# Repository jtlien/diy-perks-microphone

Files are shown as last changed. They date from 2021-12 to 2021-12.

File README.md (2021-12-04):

# diy-perks-microphone
This is the Kicad implementation of a pc board for the DIY PERKS high performance microphone
Please become a subscriber to DIY PERKS channel on Youtube.
I have put this circuit into KICAD for those interested in putting it on a PC board.
I have not tested the board out yet.
The connection to the Volume control is a switch selecting one of 560 Ohm, 270 Ohm, 150 Ohm, 82 Ohm,
56 Ohm, 27 Ohm, 18 Ohm, 15 Ohm, 11 Ohm, 9.1 Ohm and 5.1 Ohm.
The microphone connection is to a 2N4416 Fet soldered directly to the outputs of the microphone cell.
The microphone capsule is a JLI2555.  I have included a .dxf file of the capsule case that has holes for the
sound.  It can be used to have the case made at an online laser cutting service.

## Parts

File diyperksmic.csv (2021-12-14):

Id | Designator | Package | Quantity | Designation | Supplier and ref
1 | J1 | PinHeader_1x03_P2.54mm_Vertical | 1 | Conn_01x03
2 | REF**,REF**,REF**,REF** | MountingHole_2.2mm_M2_DIN965 | 4 | MountingHole_2.2mm_M2_DIN965
3 | J2 | CUI_RCJ-042 | 1 | Conn_Coaxial
4 | R1 | R_Axial_DIN0309_L9.0mm_D3.2mm_P12.70mm_Horizontal | 1 | 2.2K
5 | R2,R4,R3 | R_Axial_DIN0309_L9.0mm_D3.2mm_P15.24mm_Horizontal | 3 | 2.2K
6 | C6,C7,C3,C4 | CP_Radial_D10.0mm_P3.80mm | 4 | 2200uF
7 | J4,J3 | TerminalBlock_Phoenix_MKDS-1,5-2_1x02_P5.00mm_Horizontal | 2 | Conn_01x02
8 | R8,R7 | R_Axial_DIN0309_L9.0mm_D3.2mm_P15.24mm_Horizontal | 2 | 100
9 | R6,R5 | R_Axial_DIN0309_L9.0mm_D3.2mm_P15.24mm_Horizontal | 2 | 3.9K
10 | U2 | Converter_DCDC_muRata_NMAxxxxSC_THT | 1 | NMA0515SC
11 | U1 | DIP-8_W7.62mm | 1 | THAT1512
12 | C1,C2,C5 | C_Disc_D8.0mm_W5.0mm_P5.00mm | 3 | 22uF

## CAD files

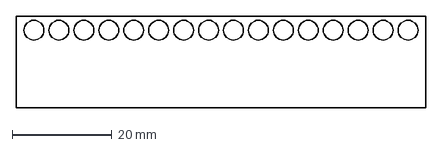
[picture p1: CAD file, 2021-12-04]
strip2.dxf
82.0 x 18.2 mm

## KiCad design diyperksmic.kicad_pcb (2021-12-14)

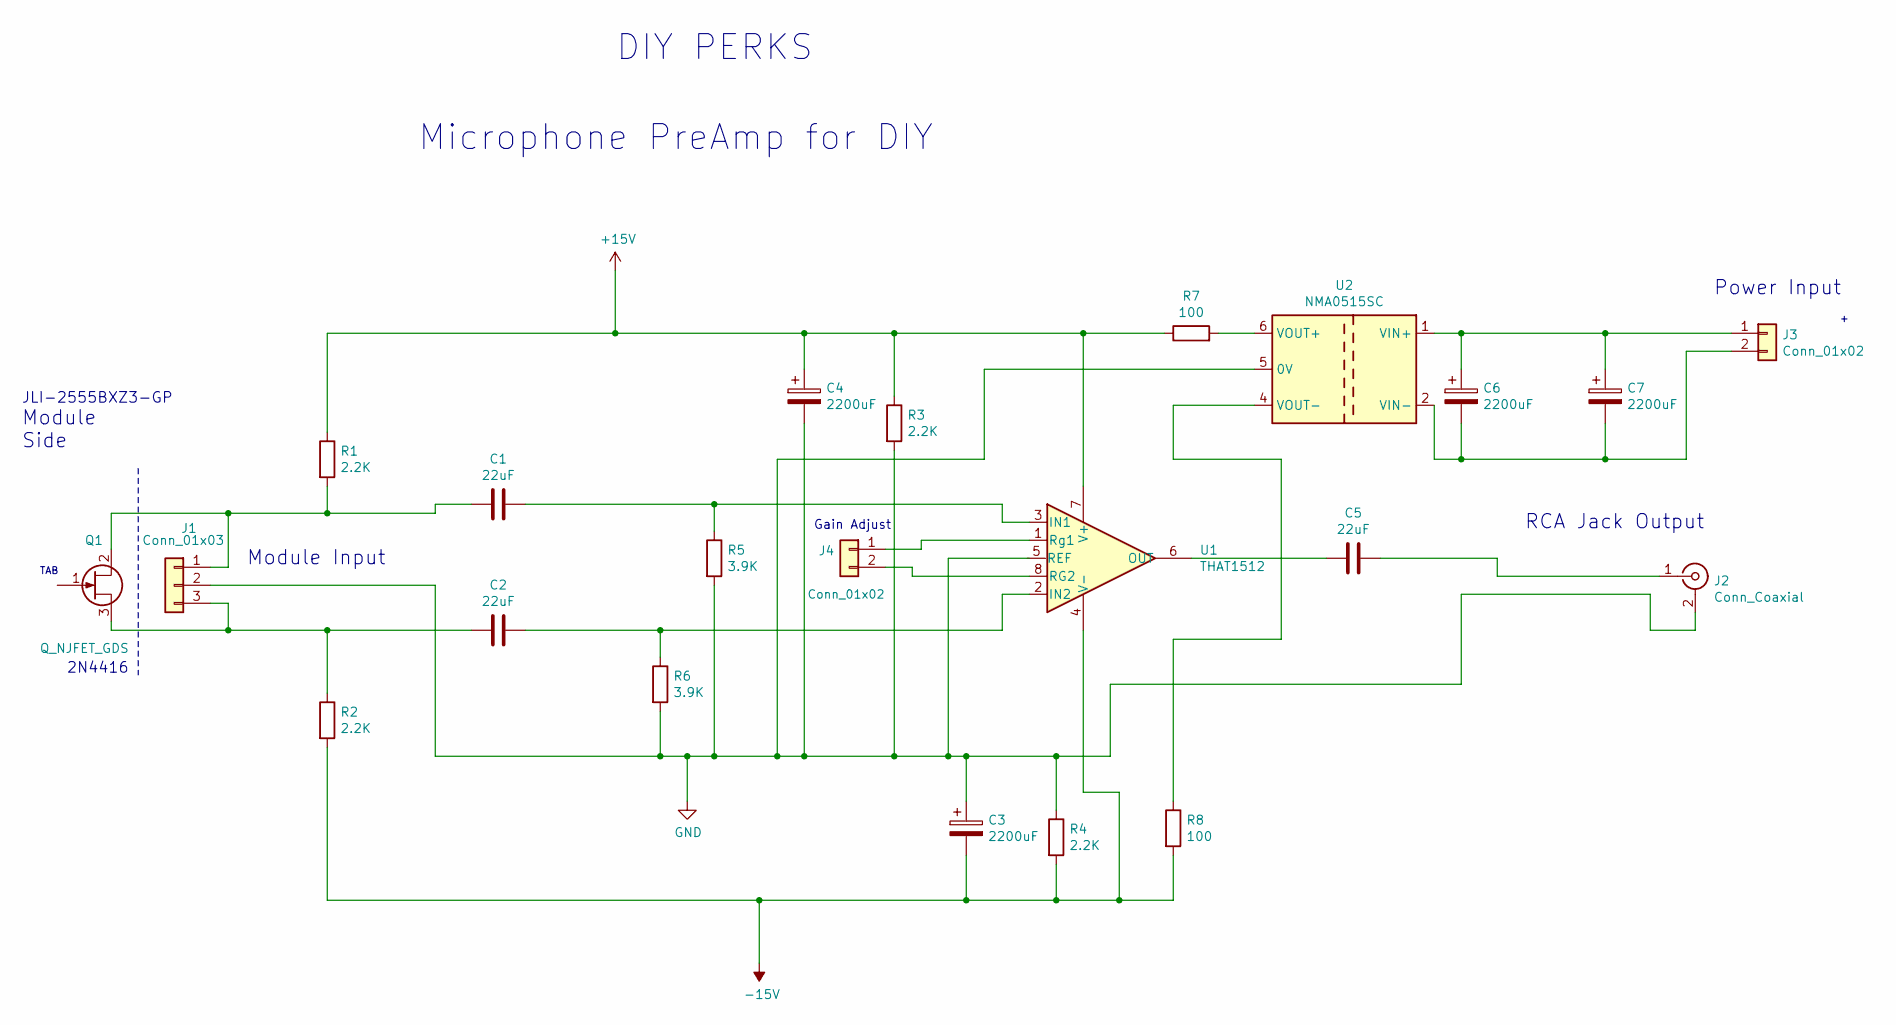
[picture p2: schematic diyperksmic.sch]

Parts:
C1, C2, C5: 22uF; C_Disc_D8.0mm_W5.0mm_P5.00mm
C3, C4, C6, C7: 2200uF; CP_Radial_D10.0mm_P3.80mm
J1: Conn_01x03; PinHeader_1x03_P2.54mm_Vertical
J2: Conn_Coaxial; CUI_RCJ-042
J3, J4: Conn_01x02; TerminalBlock_Phoenix_MKDS-1,5-2_1x02_P5.00mm_Horizontal
Q1: Q_NJFET_GDS
R1, R2, R3, R4: 2.2K; R_Axial_DIN0207_L6.3mm_D2.5mm_P10.16mm_Horizontal
R5, R6: 3.9K; R_Axial_DIN0207_L6.3mm_D2.5mm_P10.16mm_Horizontal
R7, R8: 100; R_Axial_DIN0207_L6.3mm_D2.5mm_P10.16mm_Horizontal
U1: THAT1512; DIP-8_W7.62mm
U2: NMA0515SC; Converter_DCDC_muRata_NMAxxxxSC_THT

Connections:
+15V: C4.1, R1.1, R3.1, R7.1, U1.7 (V+)
-15V: C3.2, R2.2, R4.2, R8.2, U1.4 (V-)
GND: C3.1, C4.2, J1.2, J2.2 (Ext), R3.2, R4.1, R5.2, R6.2, U2.5 (0V)
unnamed: C1.1, R5.1, U1.3 (IN1)
unnamed: C1.2, J1.1, Q1.2 (D), R1.2
unnamed: C2.1, R6.1, U1.2 (IN2)
unnamed: C2.2, J1.3, Q1.3 (S), R2.1
unnamed: C5.1, J2.1 (In)
unnamed: C5.2, U1.6 (OUT)
unnamed: C6.1, C7.1, J3.1, U2.1 (VIN+)
unnamed: C6.2, C7.2, J3.2, U2.2 (VIN-)
unnamed: J4.1, U1.1 (Rg1)
unnamed: J4.2, U1.8 (RG2)
unnamed: R7.2, U2.6 (VOUT+)
unnamed: R8.1, U2.4 (VOUT-)

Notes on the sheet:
Microphone PreAmp for DIY
2N4416
DIY PERKS
Gain Adjust
Power Input
RCA Jack Output
Module Input
Module Side
JLI-2555BXZ3-GP
TAB

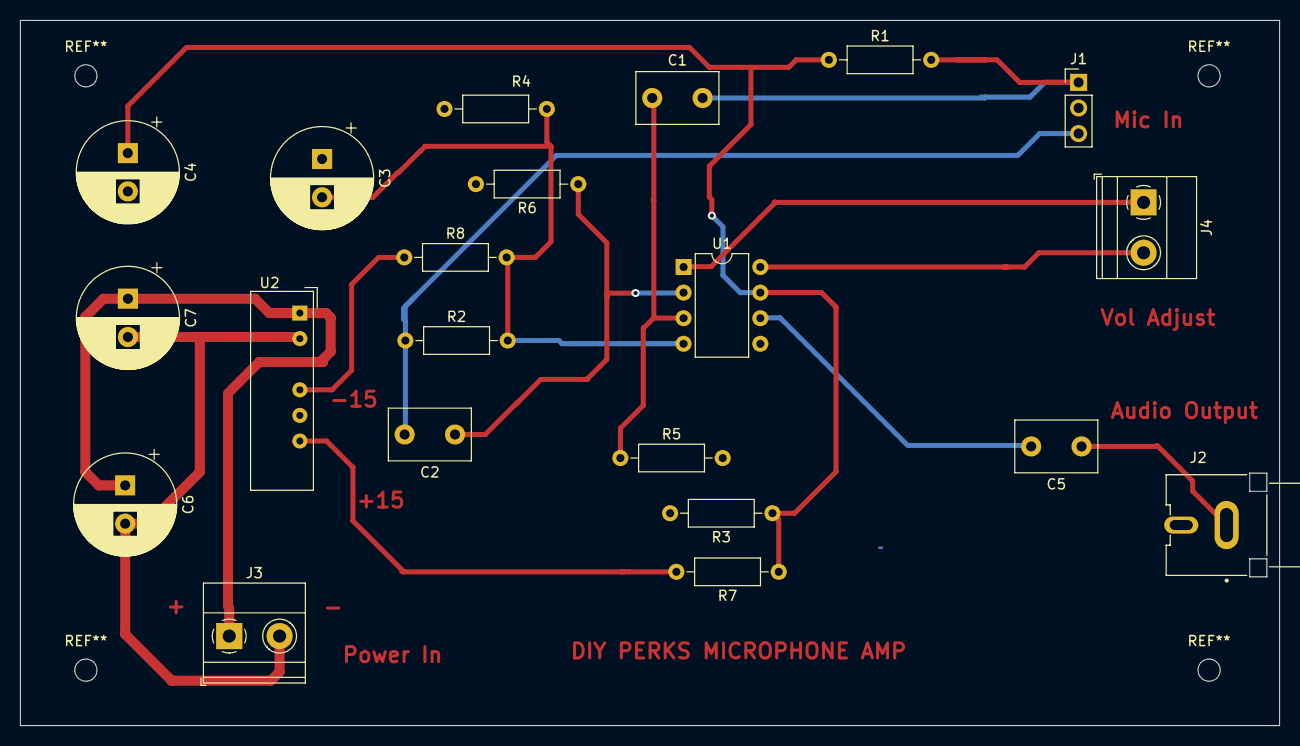
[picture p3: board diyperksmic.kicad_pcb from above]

Board: 2 copper layers, 125.0 x 70.0 mm, 21 parts (0 on the bottom side), 15 nets.

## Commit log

2021-12-04 kicad files initial release
    First upload
    [diyperksmic-B_Cu.gbr, diyperksmic-B_Mask.gbr, diyperksmic-B_Paste.gbr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]
2021-12-04 DXF file for microphone module added
    [strip2.dxf]
2021-12-14 updated kicad board
    fix resistor sizes and cap sizes
    [diyperksmic.csv, diyperksmic.kicad_pcb, diyperksmic.sch]
2021-12-14 more board updates
    new .pro file
2021-12-14 updated gerbers to reflect pcb changes
    new release 12/13
    [diyperksmic-B_Cu.gbr, diyperksmic-B_Mask.gbr, diyperksmic-B_Paste.gbr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]
